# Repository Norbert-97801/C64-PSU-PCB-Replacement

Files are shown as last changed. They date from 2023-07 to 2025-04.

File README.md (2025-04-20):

# C64-PSU-PCB-Replacement

## PSU PCB Replacement for the Commodore C64 PSU 902503-06

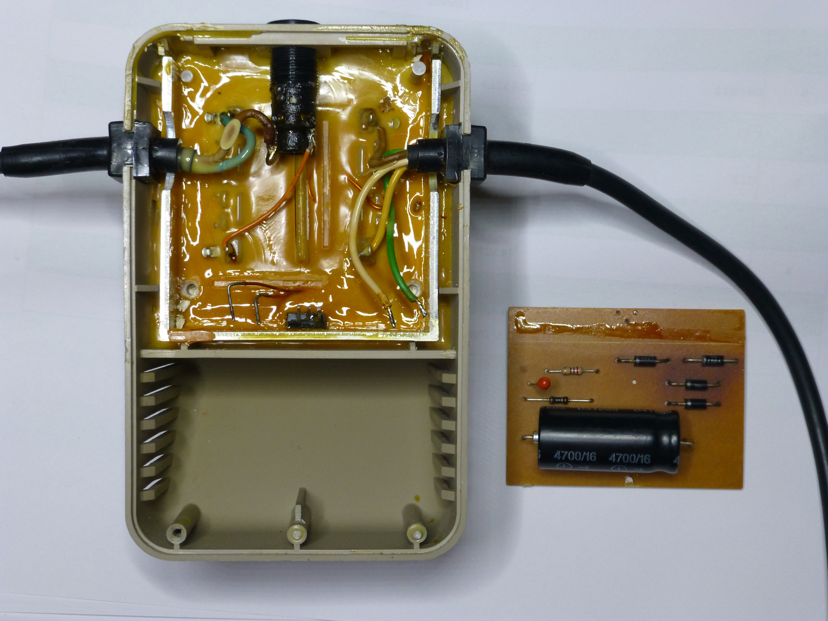
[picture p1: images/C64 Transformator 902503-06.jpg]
C64 Transformer 902503-06


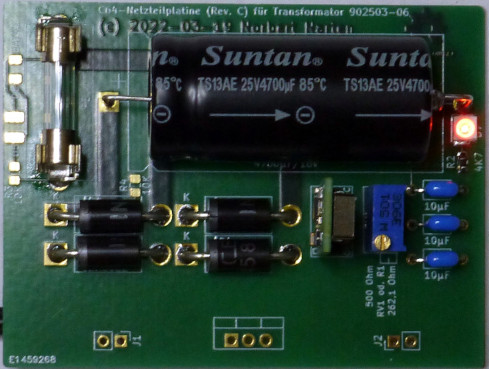
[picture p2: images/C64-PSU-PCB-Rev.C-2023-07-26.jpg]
New PCB for the C64 Power Supply Unit 902503-06
 Here is my soloution for the C64 Power Supply Unit probelm when the Power Supply Unit is going to fail or it's too old. I've developed a Power Supply Unit PCB to replace the original PCB. The build in 7805 will be used as a mounting point to install the new PCB in the Transformer housing. The new PCB is using an adjustable DC/DC Converter to get the 5.1V and there is up to 10 watts of power left that doesn't converted into heat anymore.

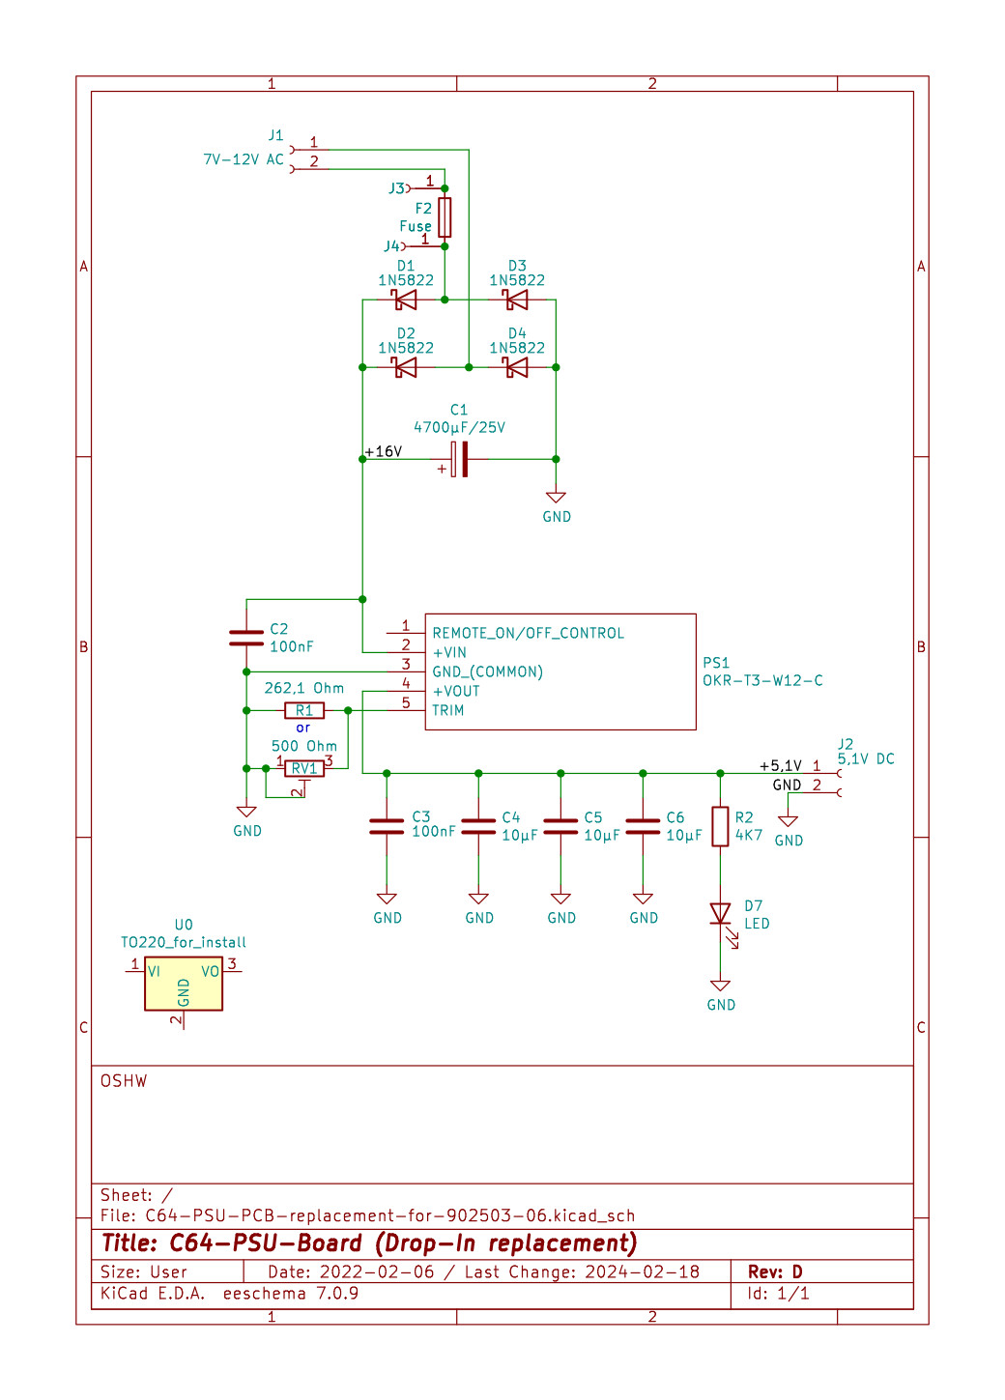
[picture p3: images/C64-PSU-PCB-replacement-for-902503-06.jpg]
Schematic


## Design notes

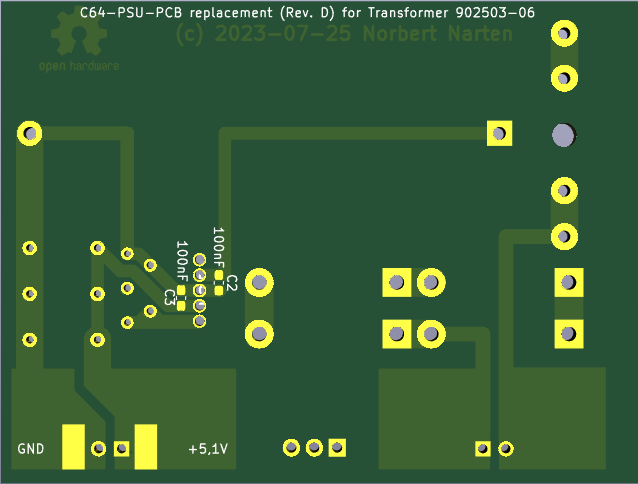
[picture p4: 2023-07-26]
images/Back.png

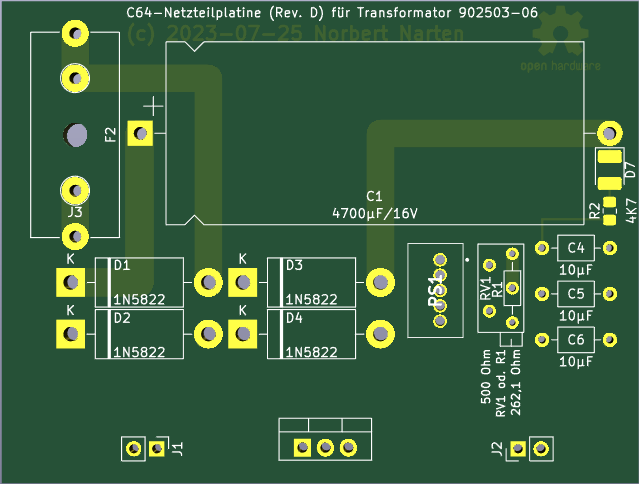
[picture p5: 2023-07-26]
images/Front.png

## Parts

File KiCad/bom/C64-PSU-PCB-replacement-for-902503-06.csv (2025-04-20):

ID | Bezeichner | Footprint | Stückzahl | Bezeichnung | Anbieter und Referenz
1 | C1 | CP_Axial_L46.0mm_D20.0mm_P52.00mm_Horizontal | 1 | 4700µF/25V
2 | C4,C5,C6 | C_Axial_L3.8mm_D2.6mm_P7.50mm_Horizontal | 3 | 10µF
3 | D1,D3,D4,D2 | D_DO-201AD_P15.24mm_Horizontal | 4 | 1N5822
4 | J1 | PinHeader_1x02_P2.54mm_Vertical | 1 | 7V-12V AC
5 | J2 | PinHeader_1x02_P2.54mm_Vertical | 1 | 5,1V DC
6 | PS1 | OKRT15W12C | 1 | OKR-T3-W12-C
7 | R1 | R_Axial_DIN0204_L3.6mm_D1.6mm_P7.62mm_Horizontal | 1 | 262,1 Ohm
8 | RV1 | Potentiometer_Bourns_3296Z_Horizontal | 1 | 500 Ohm
9 | F2 | Fuseholder_Cylinder-5x20mm_Schurter_0031_8201_Horizontal_Open | 1 | Fuse
10 | U0 | TO-220-3_Vertical | 1 | TO220_for_install
11 | J3,J4 | Pin_D1.3mm_L11.0mm | 2 | F-Mount
12 | D7 | D_1210_3225Metric_Pad1.42x2.65mm_HandSolder | 1 | LED
13 | R2 | R_0805_2012Metric_Pad1.20x1.40mm_HandSolder | 1 | 4K7
14 | GND,+5.1V | SolderWirePad_1x01_SMD_5x10mm | 2 | SolderWirePad_1x01_SMD_5x10mm
15 | C2,C3 | C_0603_1608Metric_Pad1.08x0.95mm_HandSolder | 2 | 100nF

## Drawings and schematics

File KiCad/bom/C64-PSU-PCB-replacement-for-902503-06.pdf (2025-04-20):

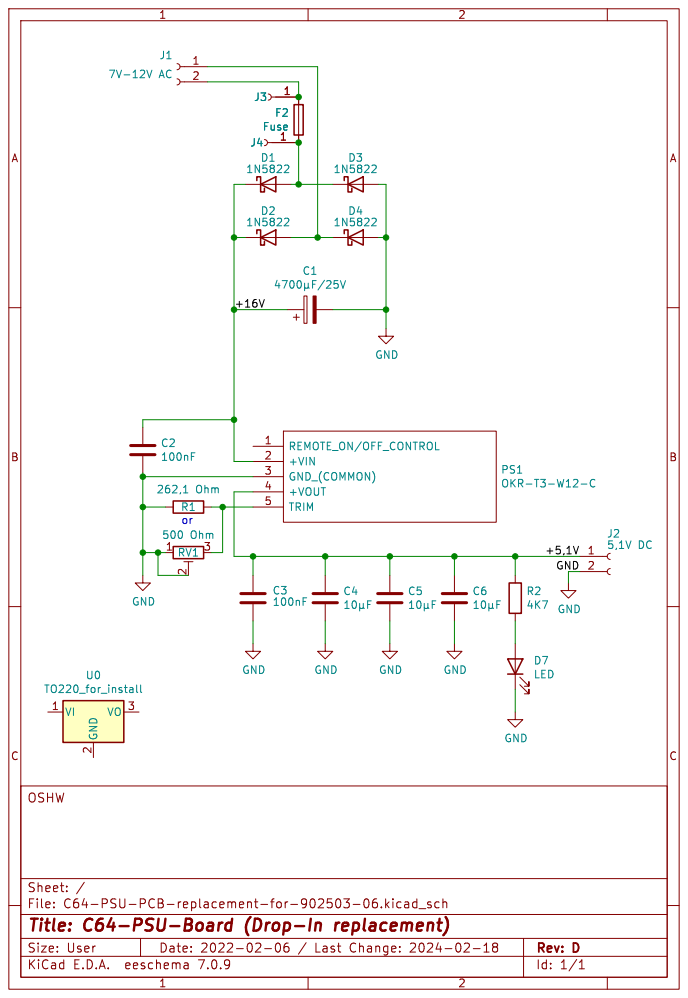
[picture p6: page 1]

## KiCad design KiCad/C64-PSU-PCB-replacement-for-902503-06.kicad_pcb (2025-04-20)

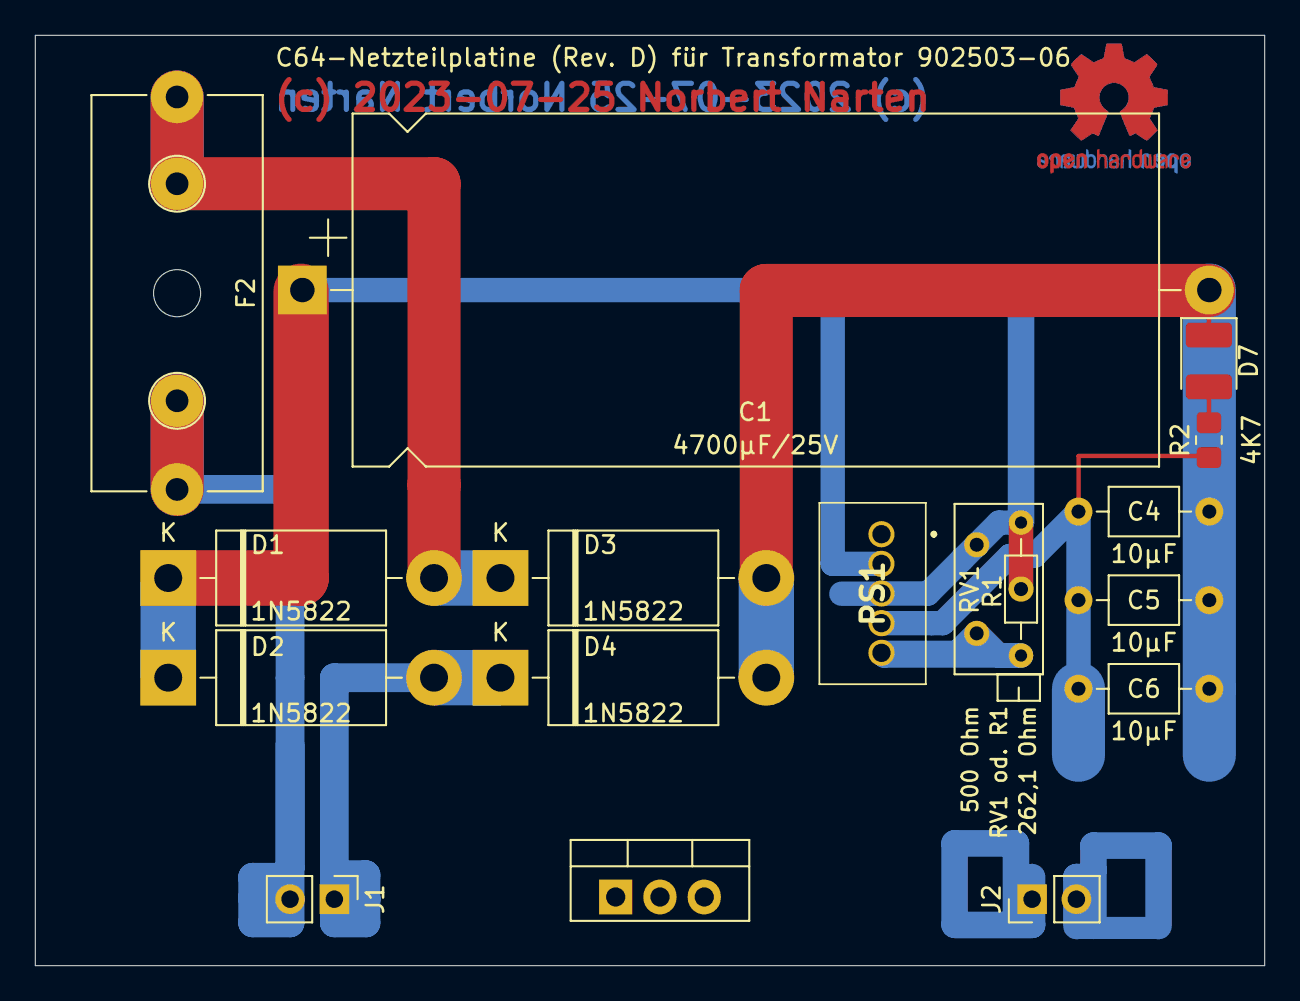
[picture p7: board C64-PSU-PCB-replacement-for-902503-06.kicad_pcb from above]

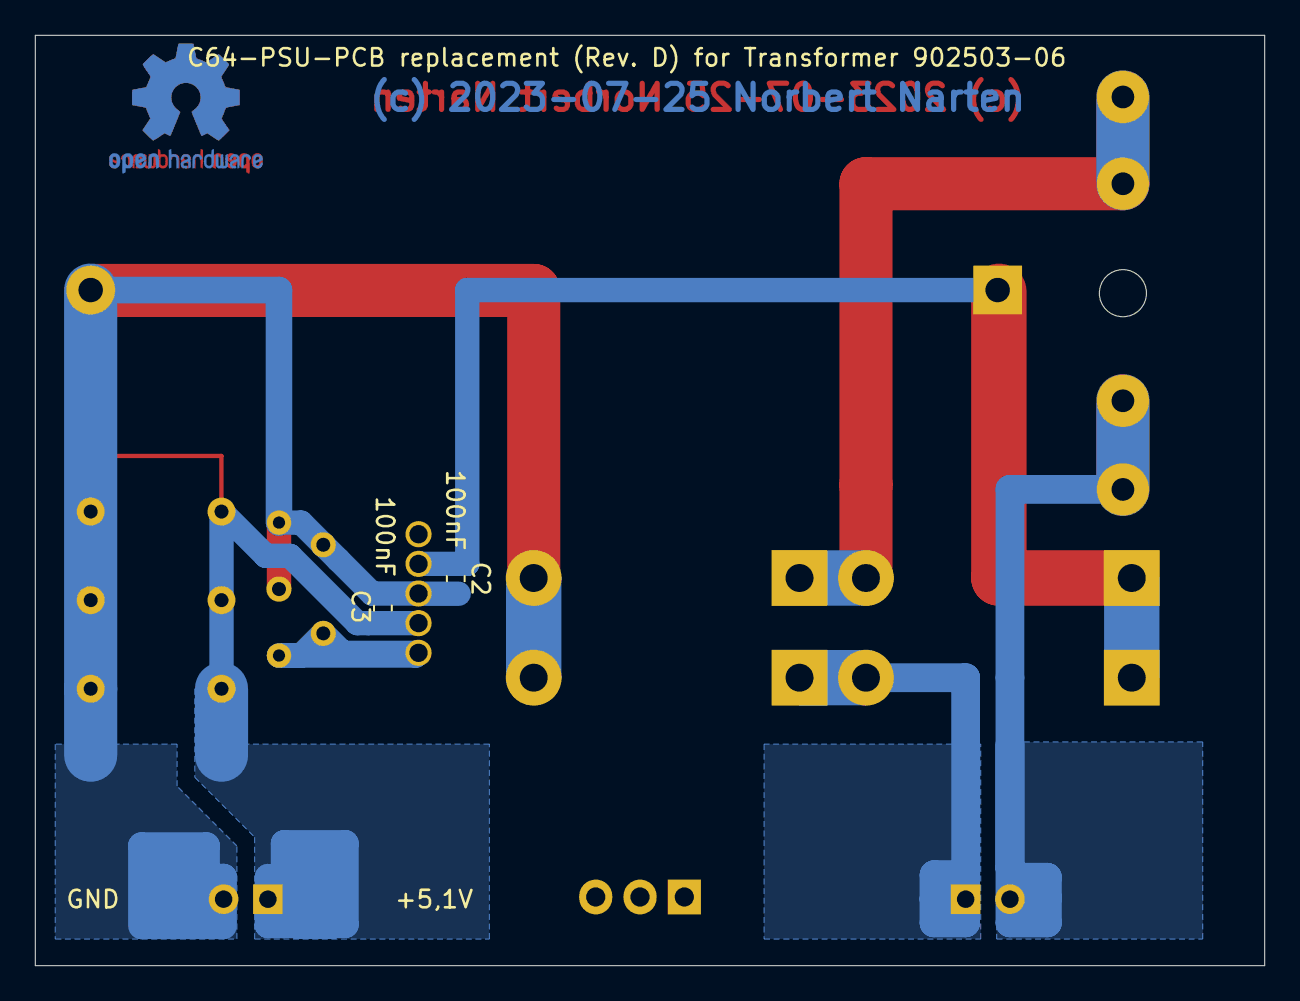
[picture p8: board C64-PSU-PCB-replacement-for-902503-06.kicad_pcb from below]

Board: 2 copper layers, 70.5 x 53.3 mm, 23 parts (4 on the bottom side), 8 nets.

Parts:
+5.1V: SolderWirePad_1x01_SMD_5x10mm
C1: 4700µF/25V; CP_Axial_L46.0mm_D20.0mm_P52.00mm_Horizontal
C2, C3: 100nF; C_0603_1608Metric_Pad1.08x0.95mm_HandSolder
C4, C5, C6: 10µF; C_Axial_L3.8mm_D2.6mm_P7.50mm_Horizontal
D1, D2, D3, D4: 1N5822; D_DO-201AD_P15.24mm_Horizontal
D7: LED; D_1210_3225Metric_Pad1.42x2.65mm_HandSolder
F2: Fuse; Fuseholder_Cylinder-5x20mm_Schurter_0031_8201_Horizontal_Op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
GND: SolderWirePad_1x01_SMD_5x10mm
J1: 7V-12V AC; PinHeader_1x02_P2.54mm_Vertical
J2: 5,1V DC; PinHeader_1x02_P2.54mm_Vertical
J3, J4: F-Mount; Pin_D1.3mm_L11.0mm
PS1: OKR-T3-W12-C; OKRT15W12C
R1: 262,1 Ohm; R_Axial_DIN0204_L3.6mm_D1.6mm_P7.62mm_Horizontal
R2: 4K7; R_0805_2012Metric_Pad1.20x1.40mm_HandSolder
RV1: 500 Ohm; Potentiometer_Bourns_3296Z_Horizontal
U0: TO220_for_install; TO-220-3_Vertical

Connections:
/+5,1V: +5.1V.1, C3.2, C4.1, C5.1, C6.1, J2.1, PS1.4 (+VOUT), R2.1
/+16V: C1.1, C2.1, D1.1 (K), D2.1 (K), PS1.2 (+VIN)
GND: C1.2, C2.2, C3.1, C4.2, C5.2, C6.2, D3.2 (A), D4.2 (A), D7.1 (K), GND.1, J2.2, PS1.3 (GND_(COMMON)), R1.2, RV1.1, RV1.2
unnamed: D1.2 (A), D3.1 (K), F2.2
unnamed: D2.2 (A), D4.1 (K), J1.1
unnamed: D7.2 (A), R2.2
unnamed: F2.1, J1.2, J3.1
unnamed: PS1.5 (TRIM), R1.1, RV1.3

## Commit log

2025-04-20 Update and rename C64-PSU-PCB-replacement-for-902503-06.pro to C64-PSU-PCB-replacement-for-902503-06.kicad_pro
2025-04-20 Update and rename C64-PSU-PCB-replacement-for-902503-06.sch to C64-PSU-PCB-replacement-for-902503-06.kicad_sch
    [C64-PSU-PCB-replacement-for-902503-06.kicad_sch, C64-PSU-PCB-replacement-for-902503-06.sch]

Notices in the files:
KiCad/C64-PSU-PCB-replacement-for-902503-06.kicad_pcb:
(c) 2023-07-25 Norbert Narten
